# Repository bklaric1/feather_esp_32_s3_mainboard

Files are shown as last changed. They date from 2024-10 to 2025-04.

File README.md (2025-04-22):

# feather_esp_32_s3_mainboard

## PCBs for a project at Technical University of Applied Science Augsburg

### Explanation
This repo contains the KiCad 8 files for the main board and the daughter board of the project.  
Necessary files are located in the source folders with the corresponding names, whilst the 3D-models, symbols and footprints can be found in the models, symbols, and footprints folders.  
The rules files are located in the source folders, and correspond with the [2 Layer HD Design Rules](https://community.aisler.net/t/2-layer-hd-design-rules/3732) from Aisler DE.  
The BOM files are located in the source folders in the *bom* folder. They are created using [Interactive HTML Bom](https://github.com/openscopeproject/InteractiveHtmlBom) Plugin. To view the BOM file, clone the repo and open them locally.  
The idea of the design is to make a battery powered system with [Adafruit ESP32-S3 Feather](https://www.adafruit.com/product/5477) as the microcontroller to control the e-paper display. We used the [7.5 inch tri-color electronic paper display](https://www.good-display.com/product/394.html) with the partial refresh as our e-paper display, but any e-paper display from [Good Display](https://www.good-display.com) and from [Waveshare](https://www.waveshare.com) would work, as there is an integrated 3.3V to 5V Boost-Converter which can be turned on if needed (per switch).  
The system is made up from two main PCBs, one that houses the microcontroller and the other which serves as a front panel Board for the buttons.  
All the parts, except the microcontroller, are sponsored by Würth Elektronik. Many thanks to them, as without them sponsoring the parts, the production of the boards would be too expensive for a student project.  
The case for the display, PCBs, and the battery pack are all designed by us and 3D printed.  

### Mainboard
The main board houses the already mentioned Adafruit ESP32-S3 Feather microcontroller. We used the version with 4 MB Flash and 2 MB PSRAM, as we needed the RAM to store a part of firmware on it (static images). The pinout is the same as some other version, so the PCB Design can be used with them as well.  
As already mentioned, there is a 3.3V to 5V Boost-Converter implemented on the board. It is found in the configuration provided by the Würth Elektronik. To switch the output voltage on the display's voltage pin, one needs to only move the switch in another position, as labeled on the board.  
The pinout for the display connector corresponds to the two display manufactures I mentioned above, but check the pinouts before connecting.  
The connector for the board is the connector that links the two boards together.  
Implementation of the external reset button isn't fully finished, but rather left as two pins on the board. I wasn't sure if we'll need to move the reset button somewhere more accessible, so I left it like that. There is no need for another reset button on the board because the microcontroller already features a built-in reset button.  
I also brought the IIC pins out on the board, in case a sensor is need later. These pins are already used internally for the battery monitoring through the MAX17048 chip.  
The battery connection is found directly on the microcontroller module. It is the JST 2-PH plug.  
The microSD adapter is designed by the specification of the espressif themselves, according to their [README](https://github.com/espressif/esp-idf/blob/master/examples/storage/sd_card/sdmmc/README.md). I also fully modified the design to make it possible to switch from the 4-wire connection (SD mode) to the 1-wire connection (SPI), in case we need more GPIO pins for something else.

### Daugtherboard
The design of the daughter board is very simple. It only includes the four buttons with the debouncing design respectively. 
The connector links with the main board to make the system complete.
Board only has one mounting hole, because of the maximum length constrains. We designed the plugin spot for the board on one side, similar to the M.2 SSD mounting technology.

### Battery Pack
As we needed to build a battery powered system, we researched and put together a battery pack with 10 600 mAh and the nominal voltage of 3.7V (4.2V) fully charged.  
The battery pack consists of two 21700 Li-Ion batteries. We have chosen [these](https://www.akkuteile.de/lithium-ionen-akkus/21700/bak/bak-n21700cd-53e-mit-5300mah-10a-3-6v-3-7v-li-ionen-akku_100625_3323) because of the high capacity and small form factor.  
Though any combination of the batteries would work, we decided to maximize the space we have in the case and the budget of our project. That is why we selected these specific cells.  
We also included the already developed [BMS](https://www.akkuteile.de/1s-pcb-keeppower-xzd-1s5530-schutzelektronik-7a_200501_1407) (Battery Management System) PCB to protect the batteries of the deep discharge, overcharge and short circuit.

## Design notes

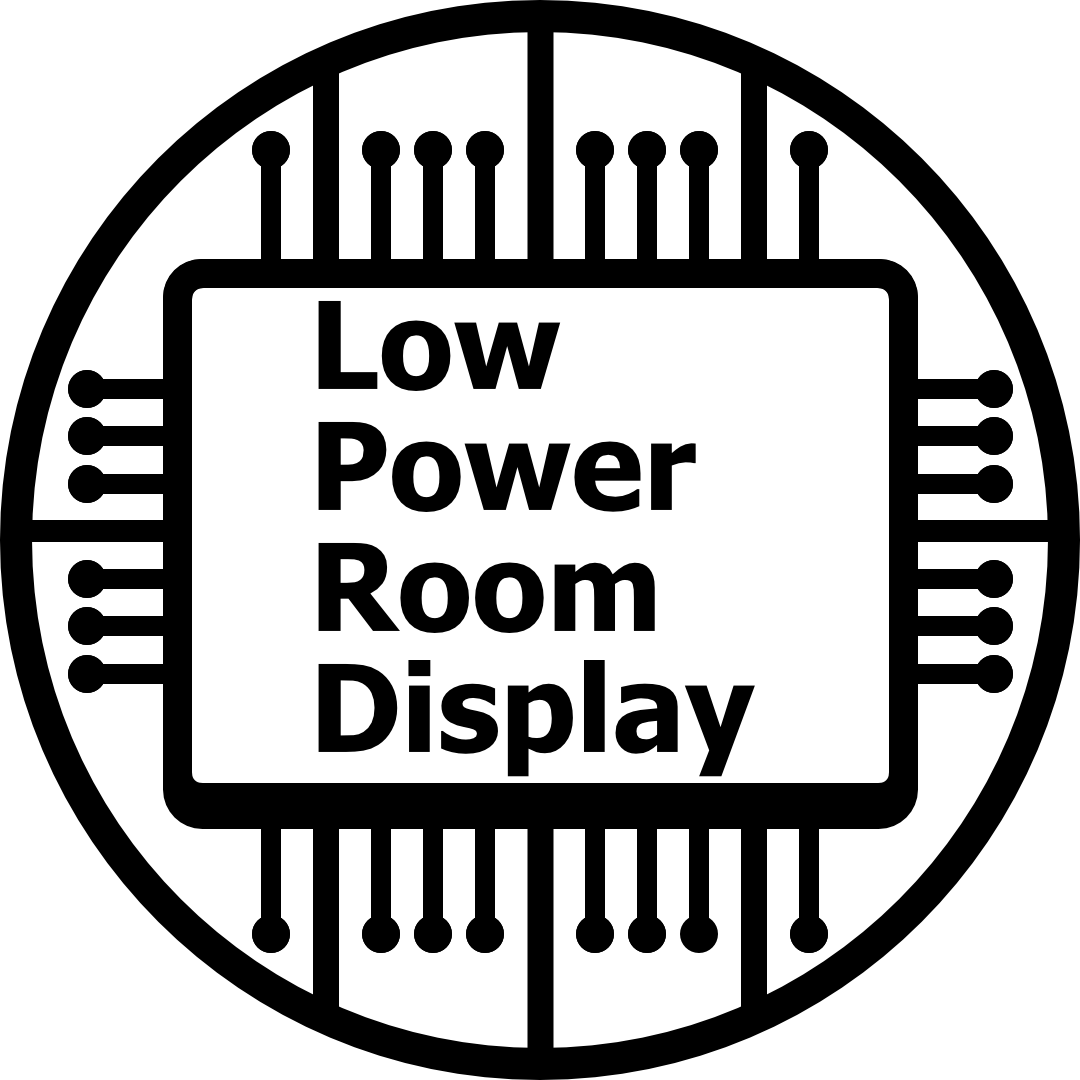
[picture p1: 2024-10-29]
models/Outline.png

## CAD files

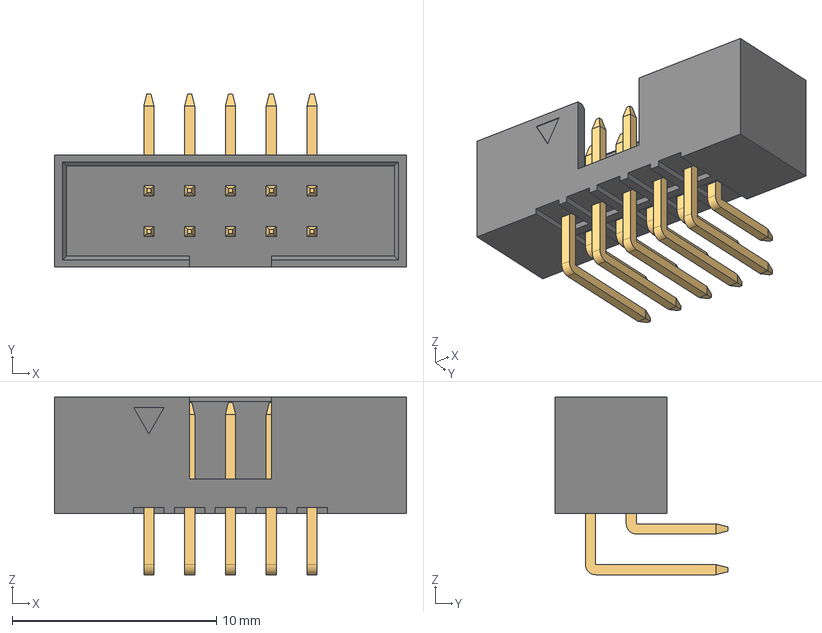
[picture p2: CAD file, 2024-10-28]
models/6250XX21721_62501021721.step
17.2 x 8.50 x 8.70 mm
6250xx21721_PIN x 5
6250xx21721_PIN_LONG x 5

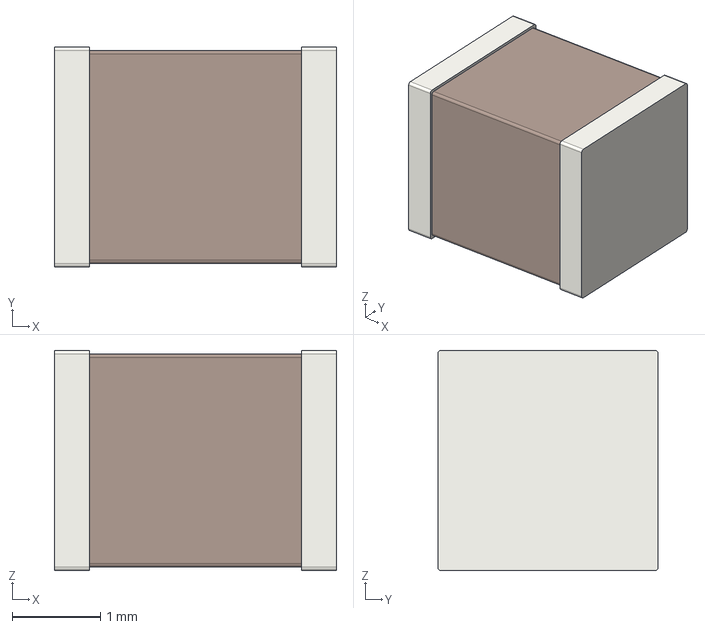
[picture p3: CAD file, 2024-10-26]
models/C_1210_3225Metric.step
3.20 x 2.50 x 2.50 mm

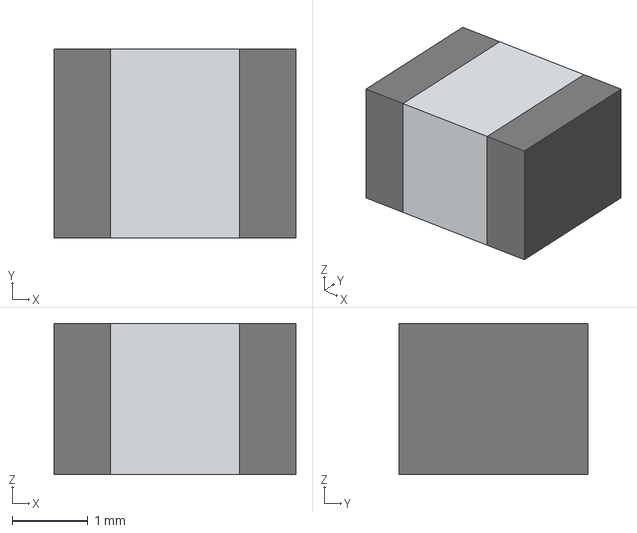
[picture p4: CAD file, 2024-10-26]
models/STP_885012x090xx (rev1).stp
3.20 x 2.50 x 2.00 mm
Body_3.2x2.5x2.0x0.75
Contact_2.5x2x0.75 x 2

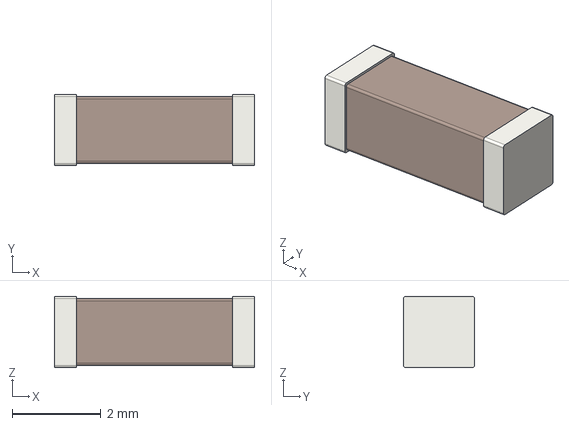
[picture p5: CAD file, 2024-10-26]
models/C_1806_4516Metric.step
4.50 x 1.60 x 1.60 mm

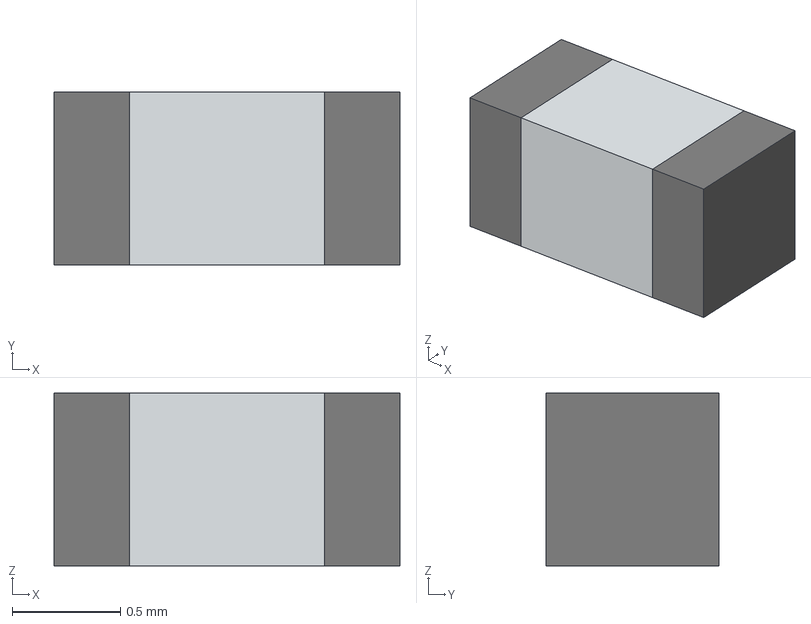
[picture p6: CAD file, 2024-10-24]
models/WCAP-CSGP_0603.step
1.60 x 0.8 x 0.8 mm
Body_1.6x0.8x0.8x0.35
Contact_0.8x0.8x0.35 x 2

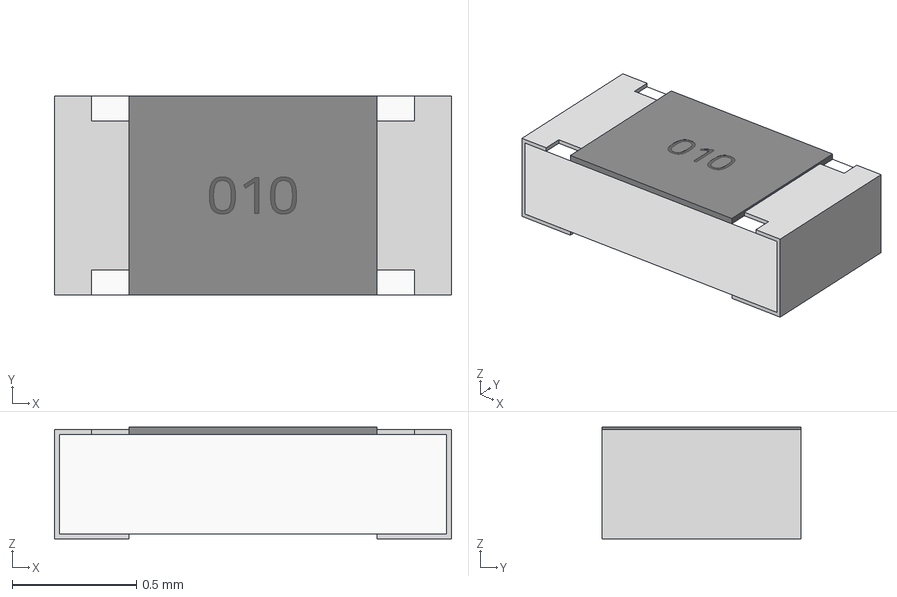
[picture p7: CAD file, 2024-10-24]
models/STP_WRIS-RSKS_0603_rev1.stp
1.60 x 0.8 x 0.45 mm
Pins
Cover

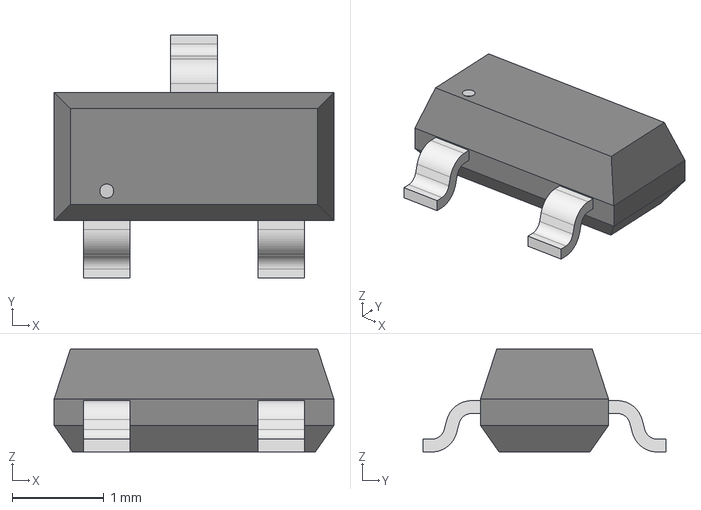
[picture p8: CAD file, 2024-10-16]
models/SOT_02K-T1-GE3_VIS.step
3.05 x 2.64 x 1.12 mm

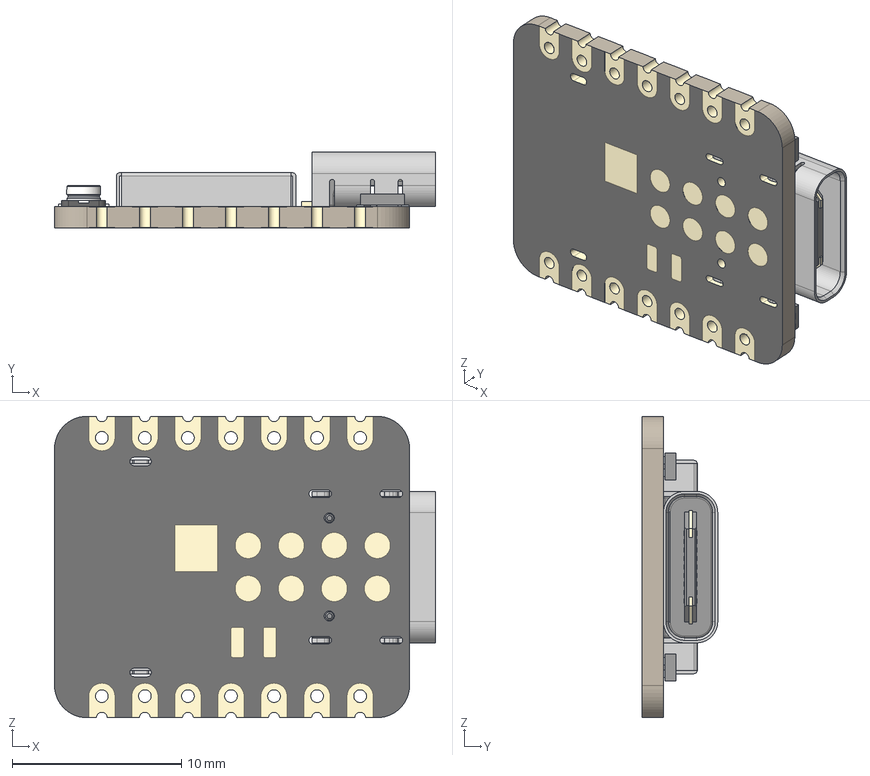
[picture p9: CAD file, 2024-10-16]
models/XIAO-ESP32S3 v2.step
22.5 x 4.46 x 17.8 mm
BOSS-EXTRUDE14_8_
BOSS-EXTRUDE7_4_
BOSS-EXTRUDE7_3_
BOSS-EXTRUDE14_4_
BOSS-EXTRUDE14_2_
BOSS-EXTRUDE14_11_
BOSS-EXTRUDE7_7_
BOSS-EXTRUDE14_9_
BOSS-EXTRUDE14_3_
BOSS-EXTRUDE14_7_
MIRROR2
BOSS-EXTRUDE14_5_
BOSS-EXTRUDE14_12_
BOSS-EXTRUDE7_8_
BOSS-EXTRUDE7_1_
BOSS-EXTRUDE14_10_
BOSS-EXTRUDE7_9_
BOSS-EXTRUDE14_6_
BOSS-EXTRUDE14_1_
BOSS-EXTRUDE7_6_
BOSS-EXTRUDE7_2_
CUT-EXTRUDE5
BOSS-EXTRUDE7_5_
Shield
Pins x 2
U.FL-R-SMT-1_10_ v1

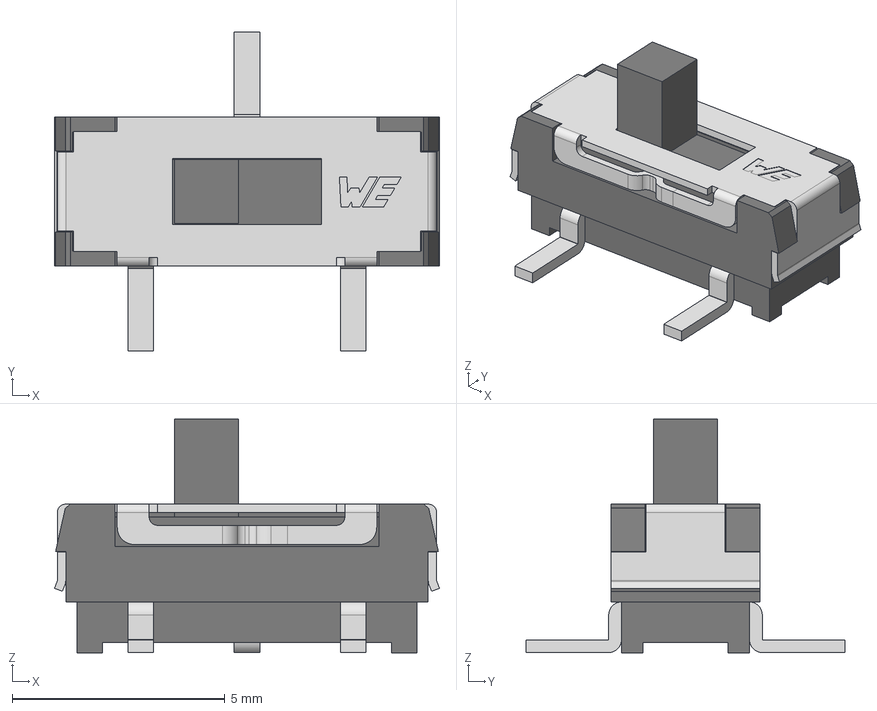
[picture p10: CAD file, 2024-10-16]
models/WS-SLSV_450406020024 (rev1).stp
9.05 x 7.50 x 5.50 mm
Base
Actuator
cover

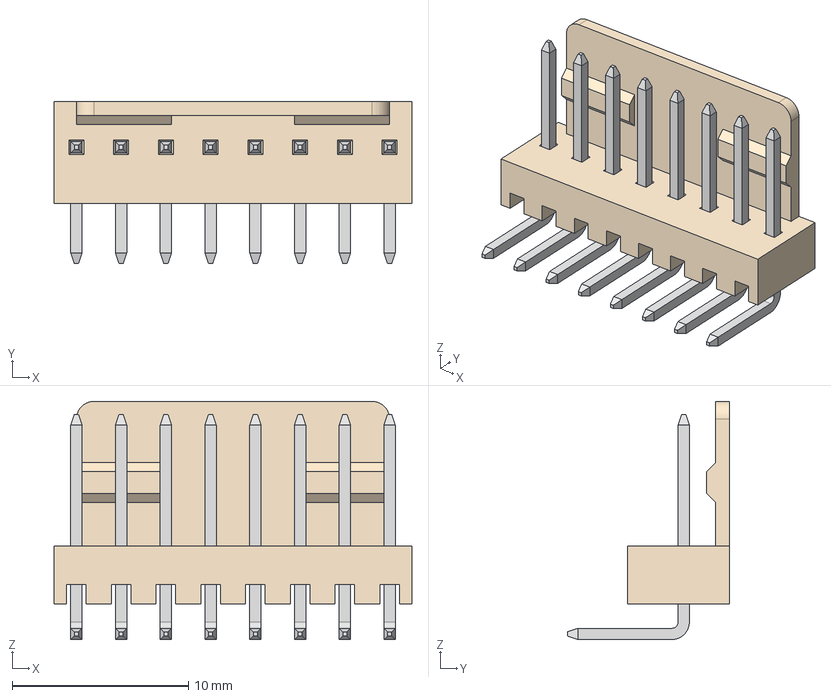
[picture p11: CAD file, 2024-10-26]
models/61900819521.step
20.3 x 9.20 x 13.5 mm
6190xx1xx21_PIN x 8

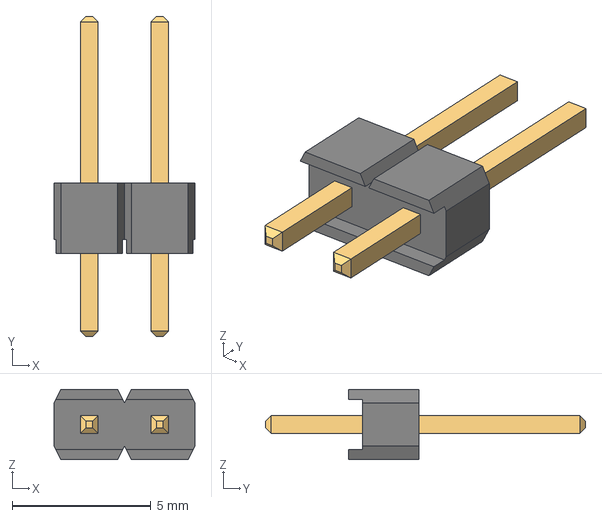
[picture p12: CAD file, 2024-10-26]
models/61300211121_rev1.stp
5.08 x 11.5 x 2.54 mm
6130xx11121_PIN x 2

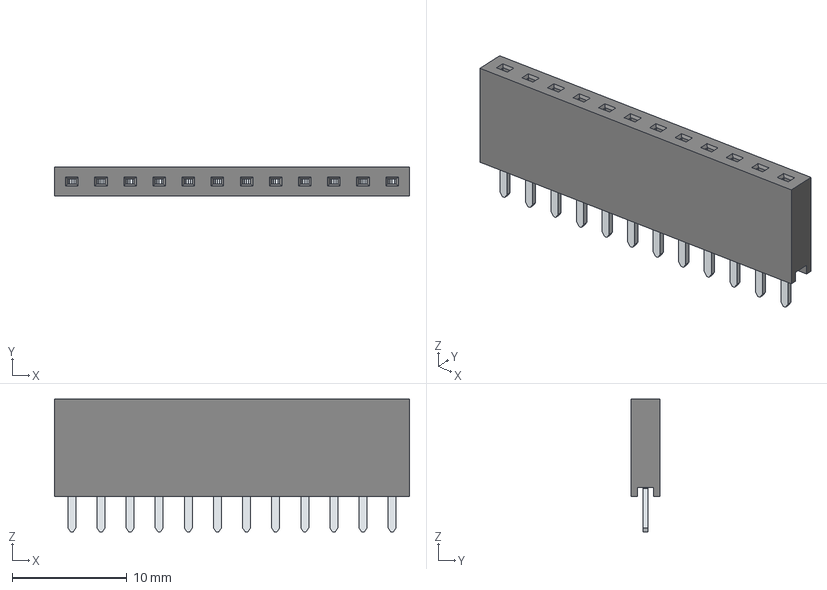
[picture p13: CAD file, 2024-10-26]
models/61301211821 (rev1).stp
31.0 x 2.50 x 11.6 mm

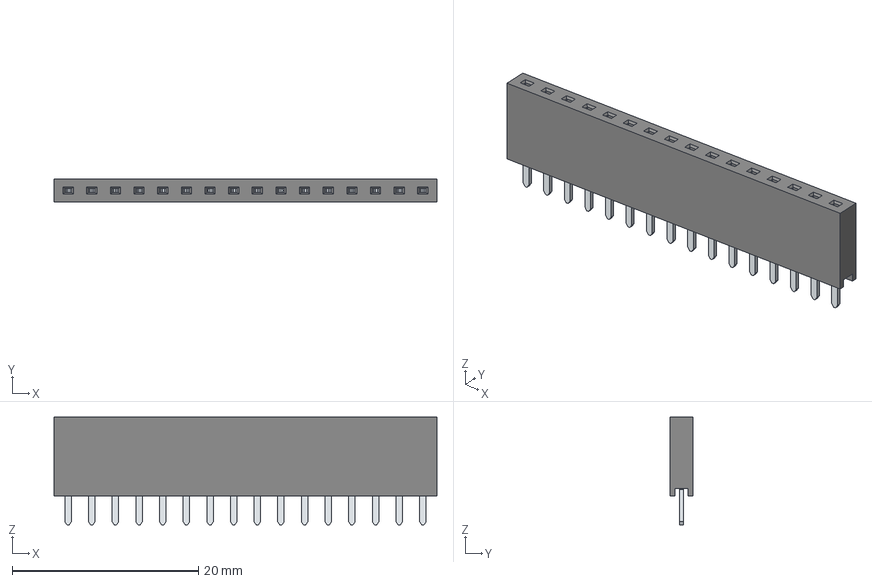
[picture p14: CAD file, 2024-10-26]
models/61301611821 (rev1).stp
41.1 x 2.50 x 11.6 mm

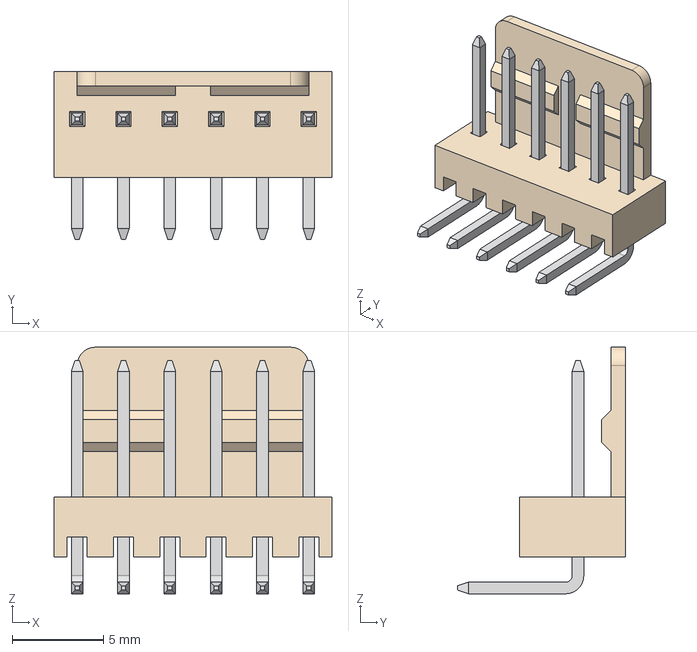
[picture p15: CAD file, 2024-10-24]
models/61900619521.step
15.2 x 9.20 x 13.5 mm
6190xx1xx21_PIN x 6

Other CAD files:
models/693071020811_rev1.stp
models/450405020524.step
models/744773033-56544.step
models/430182050816 (rev1).stp

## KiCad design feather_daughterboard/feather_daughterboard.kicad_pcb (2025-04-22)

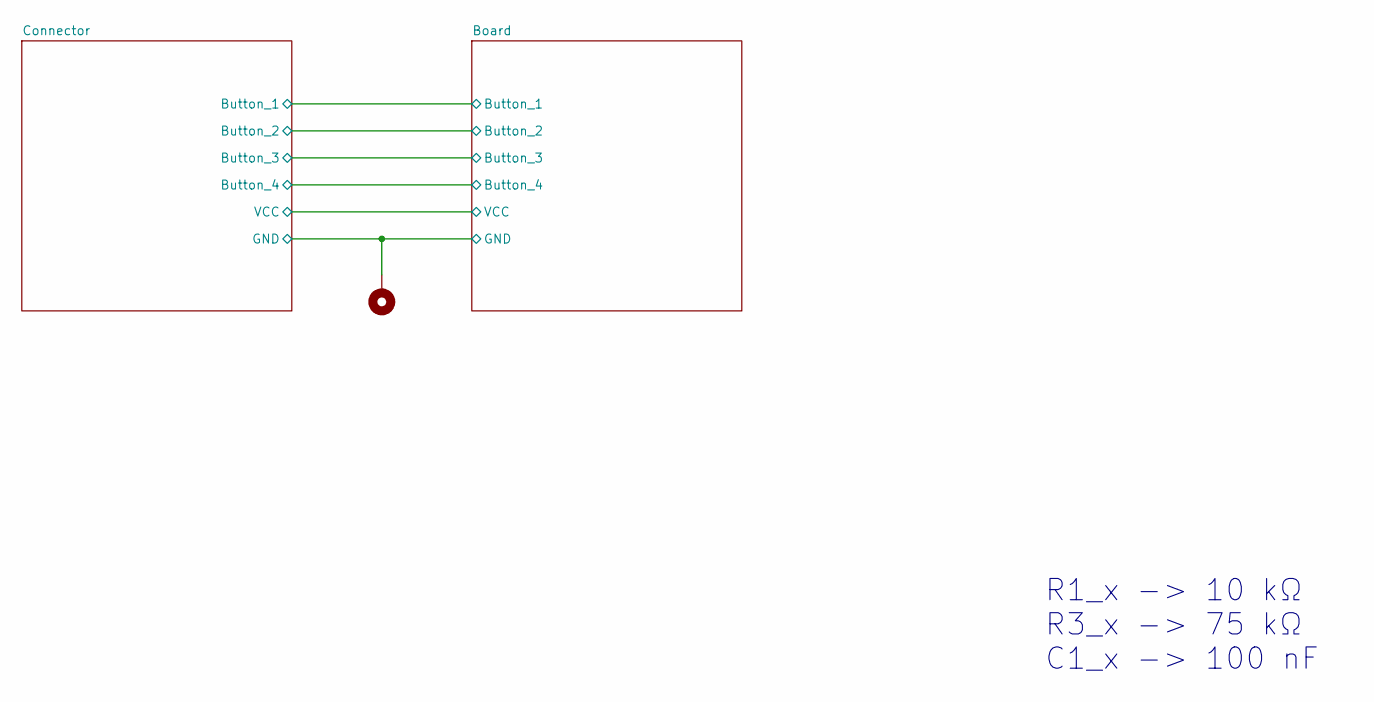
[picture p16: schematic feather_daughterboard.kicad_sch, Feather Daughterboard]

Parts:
H2: MountingHole_Pad; MountingHole_2.2mm_M2_DIN965_Pad

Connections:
/Board/GND: H2.1; also elsewhere on the board

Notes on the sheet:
R1_x -> 10 kΩ R3_x -> 75 kΩ C1_x -> 100 nF

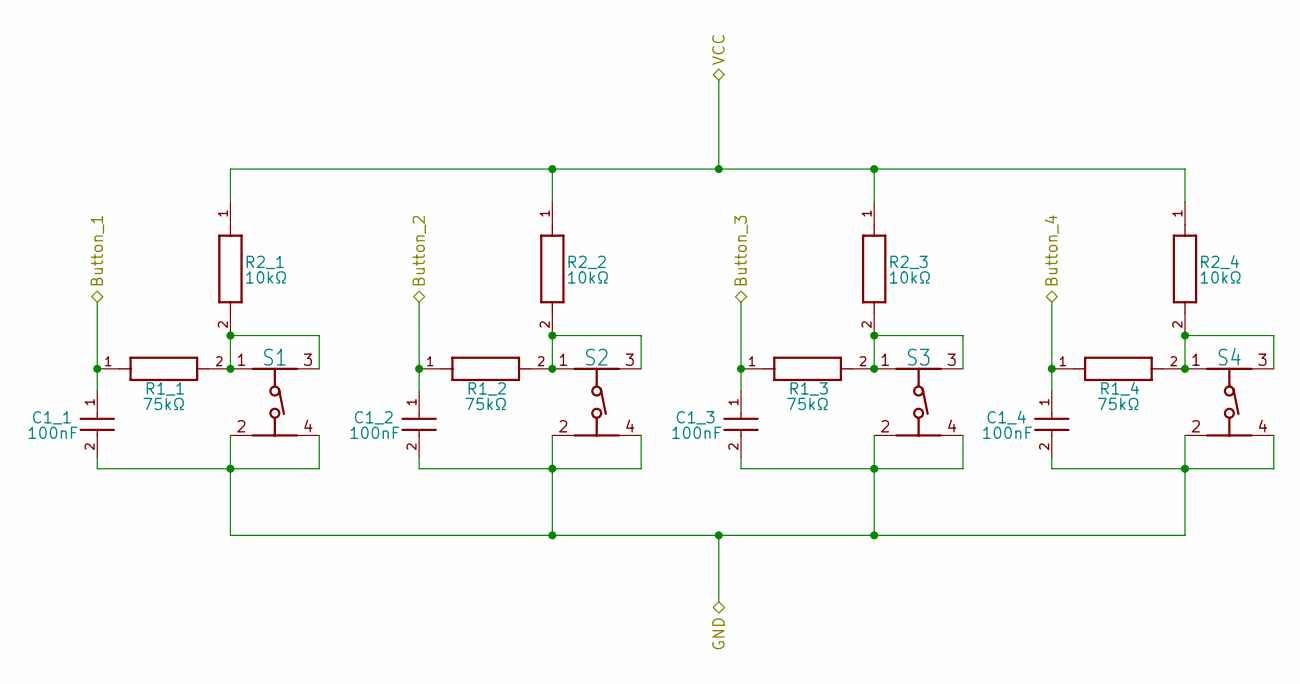
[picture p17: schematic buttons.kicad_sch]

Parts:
C1_1, C1_2, C1_3, C1_4: 100nF; WCAP-CSGP_0603_R
R1_1, R1_2, R1_3, R1_4: 75kΩ; WRIS-RSKS_0603_REFLOW
R2_1, R2_2, R2_3, R2_4: 10kΩ; WRIS-RSKS_0603_REFLOW
S1, S2, S3, S4: 430182050816

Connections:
/Board/Button_1: C1_1.1, R1_1.1; also elsewhere on the board
/Board/Button_2: C1_2.1, R1_2.1; also elsewhere on the board
/Board/Button_3: C1_3.1, R1_3.1; also elsewhere on the board
/Board/Button_4: C1_4.1, R1_4.1; also elsewhere on the board
/Board/GND: C1_1.2, C1_2.2, C1_3.2, C1_4.2, S1.2, S1.4, S2.2, S2.4, S3.2, S3.4, S4.2, S4.4; also elsewhere on the board
/Board/VCC: R2_1.1, R2_2.1, R2_3.1, R2_4.1; also elsewhere on the board
unnamed: R1_1.2, R2_1.2, S1.1, S1.3
unnamed: R1_2.2, R2_2.2, S2.1, S2.3
unnamed: R1_3.2, R2_3.2, S3.1, S3.3
unnamed: R1_4.2, R2_4.2, S4.1, S4.3

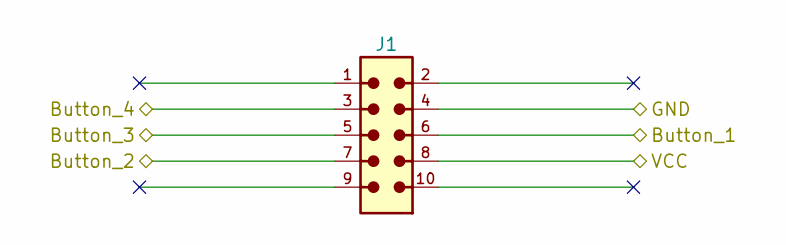
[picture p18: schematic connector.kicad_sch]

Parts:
J1: 6250XX21721_62501021721; 62501021721; PART-NUMBER 62501021721

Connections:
/Board/Button_1: J1.6; also elsewhere on the board
/Board/Button_2: J1.7; also elsewhere on the board
/Board/Button_3: J1.5; also elsewhere on the board
/Board/Button_4: J1.3; also elsewhere on the board
/Board/GND: J1.4; also elsewhere on the board
/Board/VCC: J1.8; also elsewhere on the board

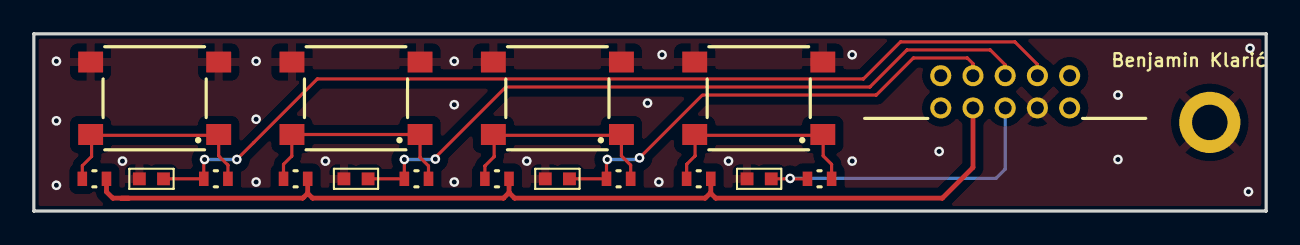
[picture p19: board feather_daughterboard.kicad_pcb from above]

Board: 2 copper layers, 76.5 x 11.0 mm, 18 parts (0 on the bottom side), 10 nets.

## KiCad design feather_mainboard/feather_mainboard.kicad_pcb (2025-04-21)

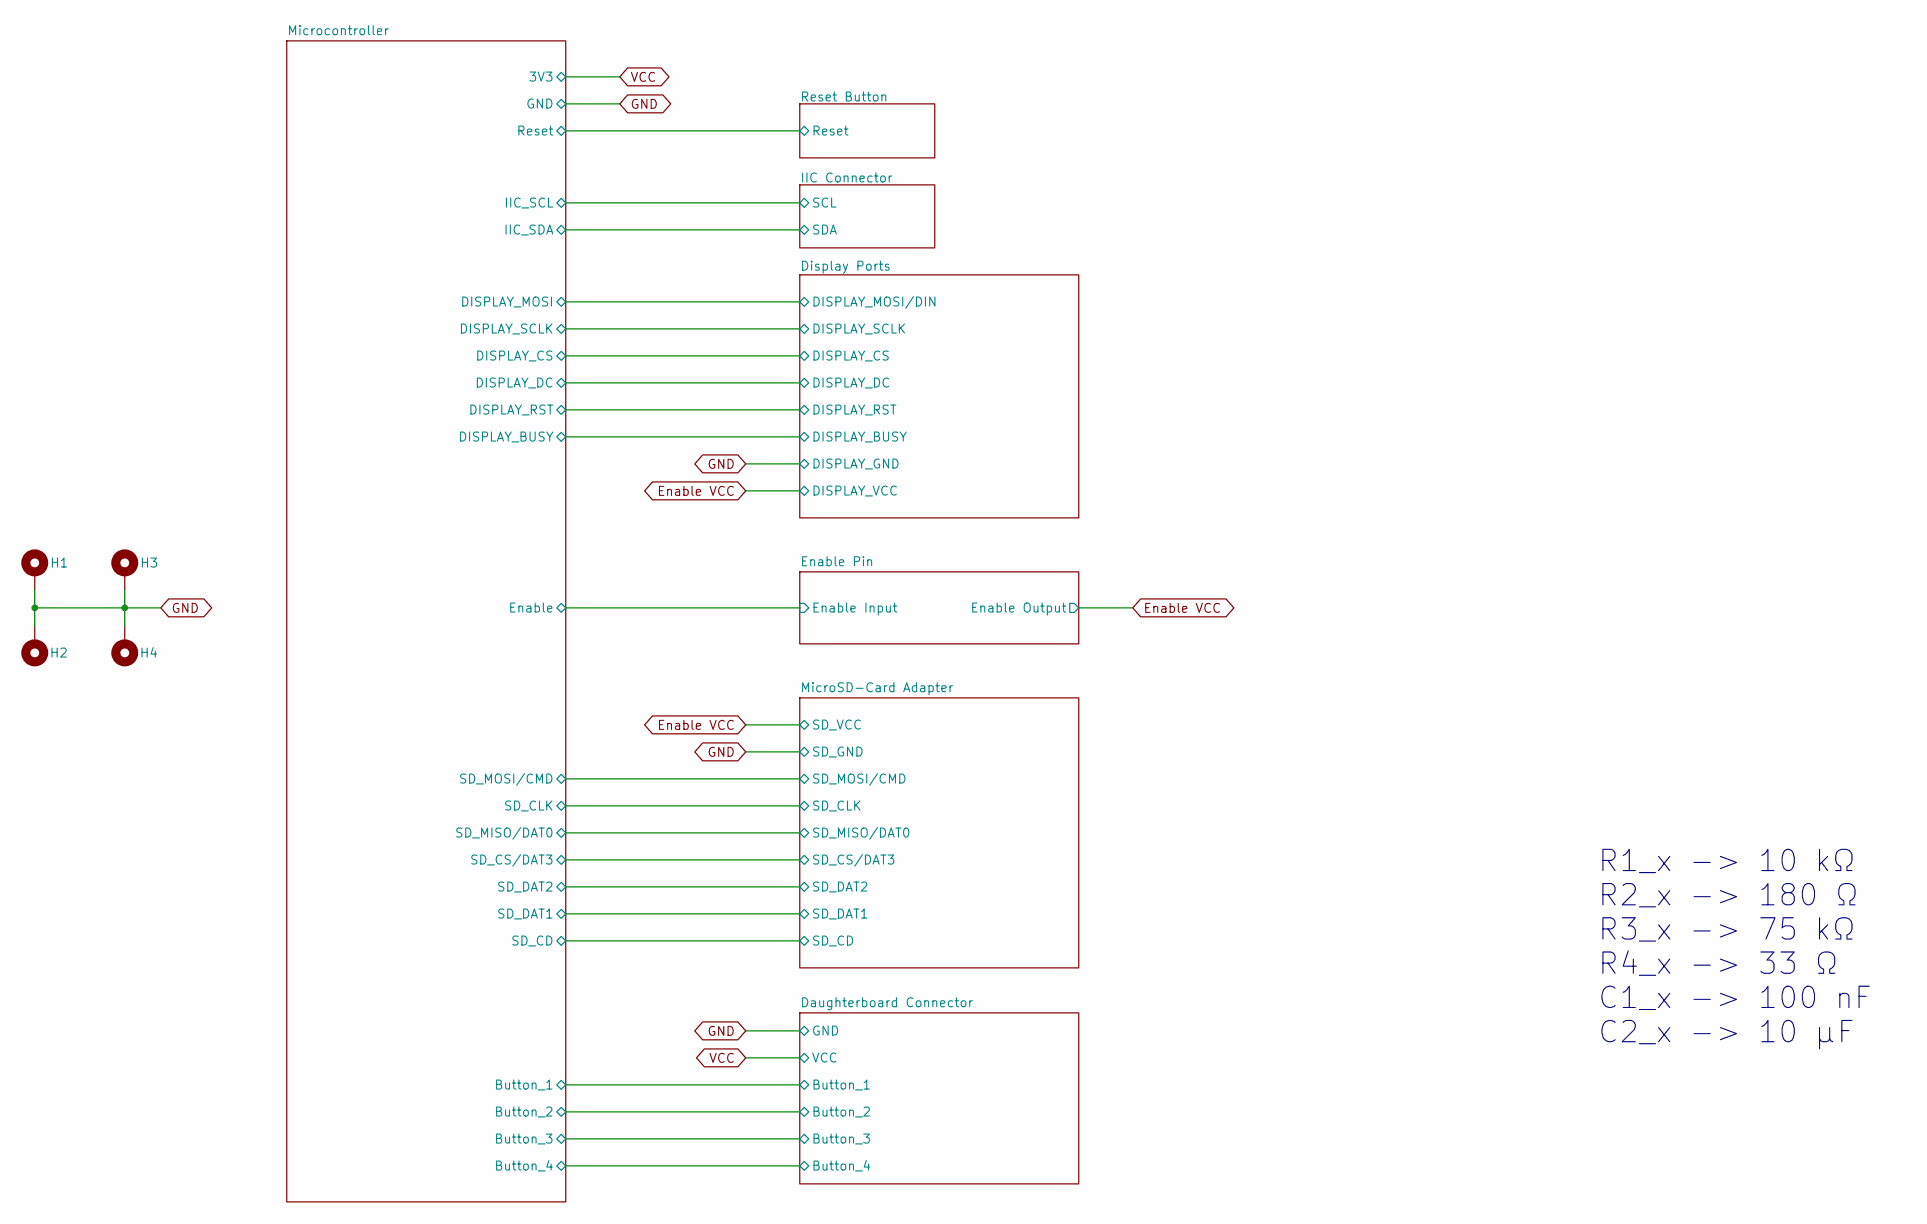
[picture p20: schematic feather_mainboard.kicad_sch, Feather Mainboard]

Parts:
H1, H2, H3, H4: MountingHole_Pad; MountingHole_2.2mm_M2_DIN965_Pad

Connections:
GND: H1.1, H2.1, H3.1, H4.1; also elsewhere on the board

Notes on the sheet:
R1_x -> 10 kΩ R2_x -> 180 Ω R3_x -> 75 kΩ R4_x -> 33 Ω C1_x -> 100 nF C2_x -> 10 µF

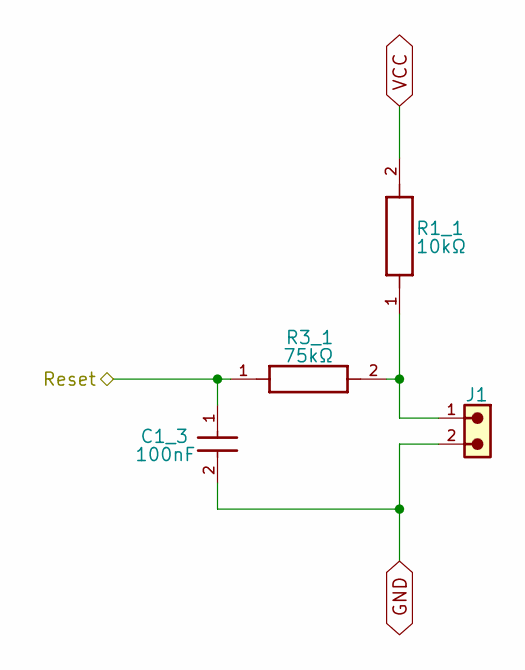
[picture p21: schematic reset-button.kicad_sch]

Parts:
C1_3: 100nF; WCAP-CSGP_0603_R
J1: 61300211121; PART-NUMBER 61300211121
R1_1: 10kΩ; WRIS-RSKS_0603_REFLOW
R3_1: 75kΩ; WRIS-RSKS_0603_REFLOW

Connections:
/Microcontroller/Reset: C1_3.1, R3_1.1; also elsewhere on the board
GND: C1_3.2, J1.2; also elsewhere on the board
unnamed: J1.1, R1_1.1, R3_1.2
VCC: R1_1.2; also elsewhere on the board

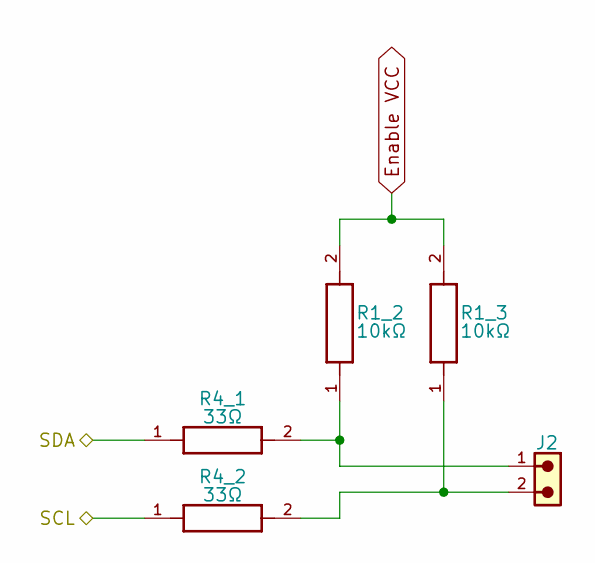
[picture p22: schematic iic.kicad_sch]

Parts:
J2: 61300211121; PART-NUMBER 61300211121
R1_2, R1_3: 10kΩ; WRIS-RSKS_0603_REFLOW
R4_1, R4_2: 33Ω; WRIS-RSKS_0603_REFLOW

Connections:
/IIC Connector/SCL: R4_2.1; also elsewhere on the board
/IIC Connector/SDA: R4_1.1; also elsewhere on the board
Enable VCC: R1_2.2, R1_3.2; also elsewhere on the board
unnamed: J2.1, R1_2.1, R4_1.2
unnamed: J2.2, R1_3.1, R4_2.2

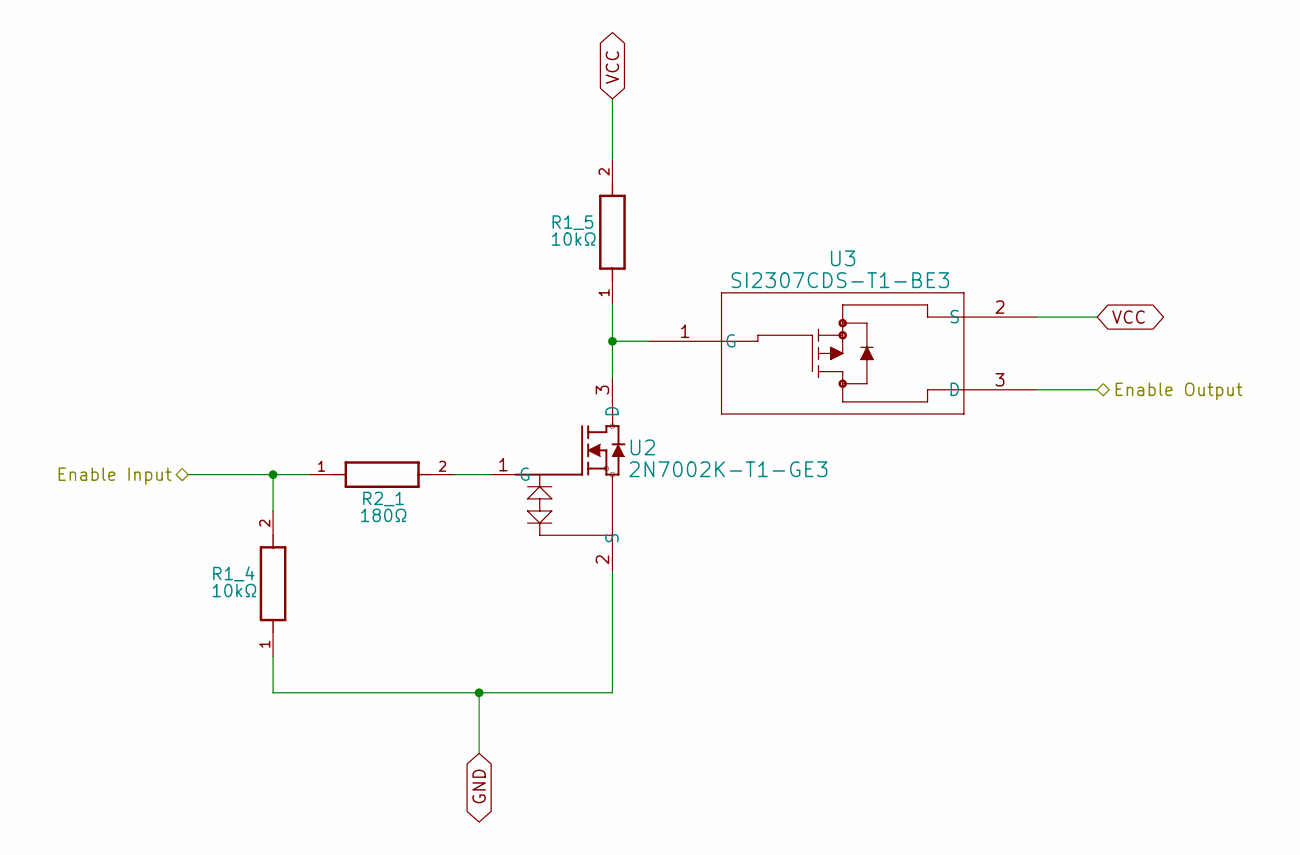
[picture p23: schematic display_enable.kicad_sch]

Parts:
R1_4, R1_5: 10kΩ; WRIS-RSKS_0603_REFLOW
R2_1: 180Ω; WRIS-RSKS_0603_REFLOW
U2: 2N7002K-T1-GE3; SOT_02K-T1-GE3_VIS
U3: SI2307CDS-T1-BE3; SOT-23_VIS

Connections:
/Enable Pin/Enable Input: R1_4.2, R2_1.1; also elsewhere on the board
Enable VCC: U3.3 (D); also elsewhere on the board
GND: R1_4.1, U2.2 (S); also elsewhere on the board
unnamed: R1_5.1, U2.3 (D), U3.1 (G)
unnamed: R2_1.2, U2.1 (G)
VCC: R1_5.2, U3.2 (S); also elsewhere on the board

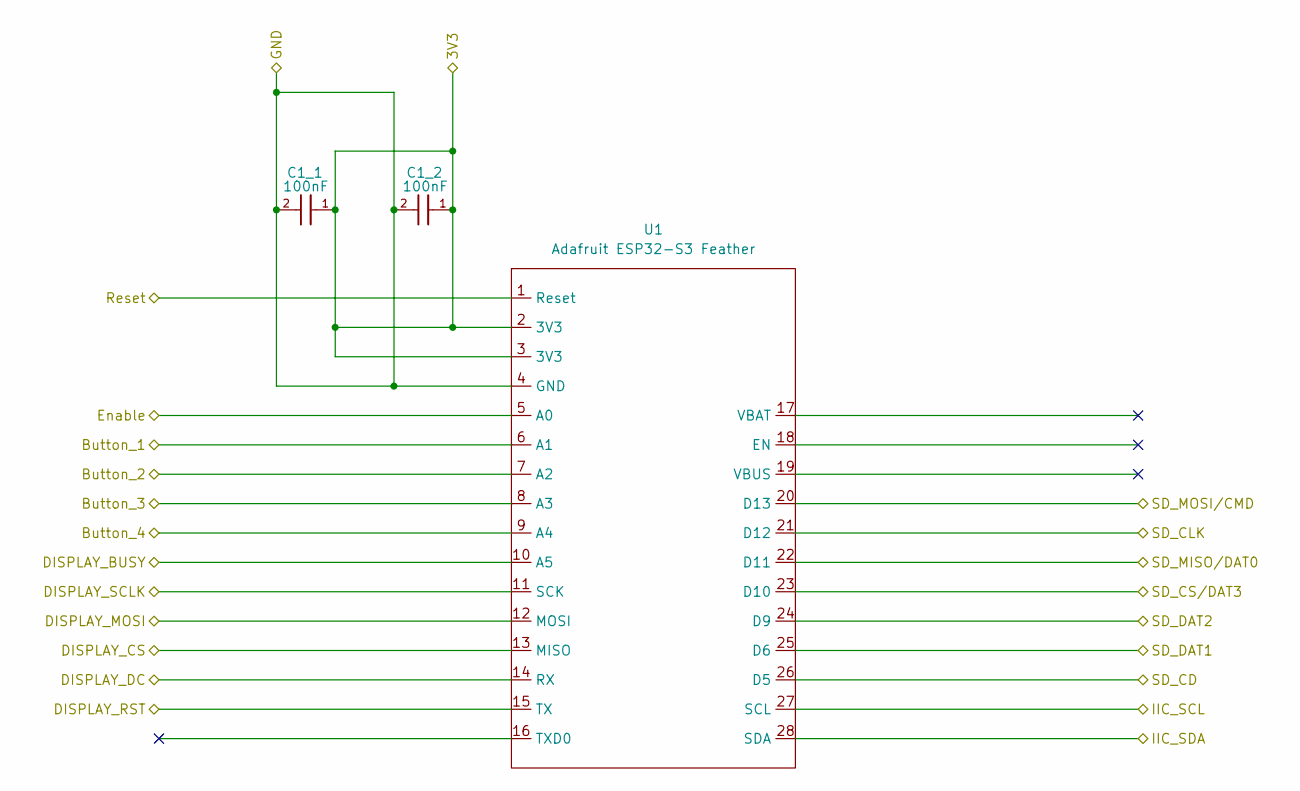
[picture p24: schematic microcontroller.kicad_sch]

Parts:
C1_1, C1_2: 100nF; WCAP-CSGP_0603_R
U1: Adafruit ESP32-S3 Feather; Adafruit ESP32-S3 Feather 4MB Flash 2MB PSRAM

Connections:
/Daughterboard Connector/Button_1: U1.6 (A1); also elsewhere on the board
/Daughterboard Connector/Button_2: U1.7 (A2); also elsewhere on the board
/Daughterboard Connector/Button_3: U1.8 (A3); also elsewhere on the board
/Daughterboard Connector/Button_4: U1.9 (A4); also elsewhere on the board
/Display Ports/DISPLAY_BUSY: U1.10 (A5); also elsewhere on the board
/Display Ports/DISPLAY_CS: U1.13 (MISO); also elsewhere on the board
/Display Ports/DISPLAY_DC: U1.14 (RX); also elsewhere on the board
/Display Ports/DISPLAY_MOSI/DIN: U1.12 (MOSI); also elsewhere on the board
/Display Ports/DISPLAY_RST: U1.15 (TX); also elsewhere on the board
/Display Ports/DISPLAY_SCLK: U1.11 (SCK); also elsewhere on the board
/Enable Pin/Enable Input: U1.5 (A0); also elsewhere on the board
/IIC Connector/SCL: U1.27 (SCL); also elsewhere on the board
/IIC Connector/SDA: U1.28 (SDA); also elsewhere on the board
/MicroSD-Card Adapter/SD_CD: U1.26 (D5); also elsewhere on the board
/MicroSD-Card Adapter/SD_CLK: U1.21 (D12); also elsewhere on the board
/MicroSD-Card Adapter/SD_CS/DAT3: U1.23 (D10); also elsewhere on the board
/MicroSD-Card Adapter/SD_DAT1: U1.25 (D6); also elsewhere on the board
/MicroSD-Card Adapter/SD_DAT2: U1.24 (D9); also elsewhere on the board
/MicroSD-Card Adapter/SD_MISO/DAT0: U1.22 (D11); also elsewhere on the board
/MicroSD-Card Adapter/SD_MOSI/CMD: U1.20 (D13); also elsewhere on the board
/Microcontroller/Reset: U1.1 (Reset); also elsewhere on the board
GND: C1_1.2, C1_2.2, U1.4 (GND); also elsewhere on the board
VCC: C1_1.1, C1_2.1, U1.2 (3V3), U1.3 (3V3); also elsewhere on the board

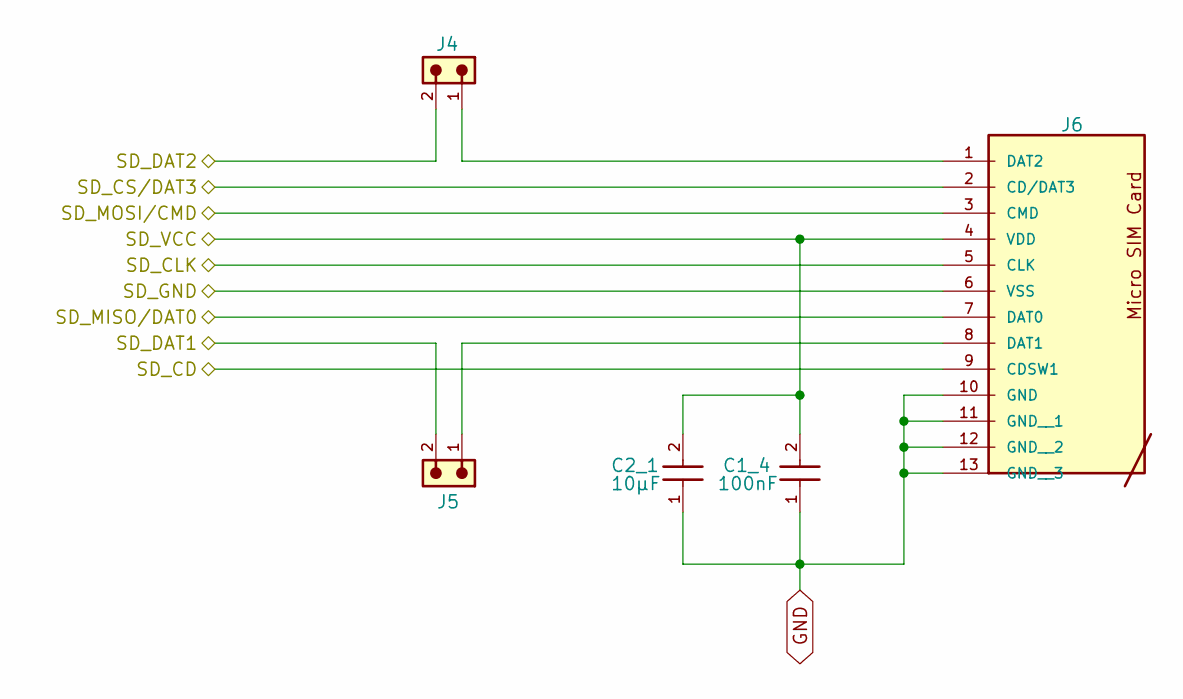
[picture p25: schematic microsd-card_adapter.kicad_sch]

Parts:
C1_4: 100nF; WCAP-CSGP_0603_R
C2_1: 10µF; WCAP-CSGP_0603_R
J4, J5: 61300211121; PART-NUMBER 61300211121
J6: 693071020811; PART-NUMBER 693071020811

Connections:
/MicroSD-Card Adapter/SD_CD: J6.9 (CDSW1); also elsewhere on the board
/MicroSD-Card Adapter/SD_CLK: J6.5 (CLK); also elsewhere on the board
/MicroSD-Card Adapter/SD_CS/DAT3: J6.2 (CD/DAT3); also elsewhere on the board
/MicroSD-Card Adapter/SD_DAT1: J5.2; also elsewhere on the board
/MicroSD-Card Adapter/SD_DAT2: J4.2; also elsewhere on the board
/MicroSD-Card Adapter/SD_MISO/DAT0: J6.7 (DAT0); also elsewhere on the board
/MicroSD-Card Adapter/SD_MOSI/CMD: J6.3 (CMD); also elsewhere on the board
Enable VCC: C1_4.2, C2_1.2, J6.4 (VDD); also elsewhere on the board
GND: C1_4.1, C2_1.1, J6.6 (VSS), J6.10 (GND), J6.11 (GND__1), J6.12 (GND__2), J6.13 (GND__3); also elsewhere on the board
unnamed: J5.1, J6.8 (DAT1)
unnamed: J4.1, J6.1 (DAT2)

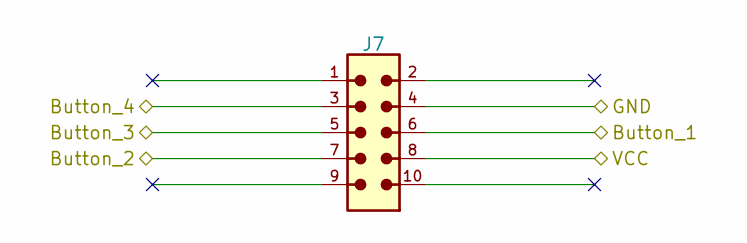
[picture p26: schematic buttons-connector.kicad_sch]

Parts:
J7: 62501021721; 62501021721_full; PART-NUMBER 62501021721

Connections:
/Daughterboard Connector/Button_1: J7.6; also elsewhere on the board
/Daughterboard Connector/Button_2: J7.7; also elsewhere on the board
/Daughterboard Connector/Button_3: J7.5; also elsewhere on the board
/Daughterboard Connector/Button_4: J7.3; also elsewhere on the board
GND: J7.4; also elsewhere on the board
VCC: J7.8; also elsewhere on the board

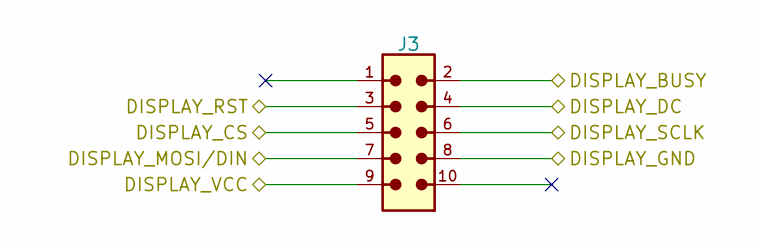
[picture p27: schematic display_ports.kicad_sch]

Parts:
J3: 62501021721; 62501021721_full; PART-NUMBER 62501021721

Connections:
/Display Ports/DISPLAY_BUSY: J3.2; also elsewhere on the board
/Display Ports/DISPLAY_CS: J3.5; also elsewhere on the board
/Display Ports/DISPLAY_DC: J3.4; also elsewhere on the board
/Display Ports/DISPLAY_MOSI/DIN: J3.7; also elsewhere on the board
/Display Ports/DISPLAY_RST: J3.3; also elsewhere on the board
/Display Ports/DISPLAY_SCLK: J3.6; also elsewhere on the board
Enable VCC: J3.9; also elsewhere on the board
GND: J3.8; also elsewhere on the board


Board: 2 copper layers, 60.0 x 60.0 mm, 28 parts (0 on the bottom side), 31 nets.

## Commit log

2024-10-16 added parts of the schematics that were already used by the xiao_mainboard, as we want to be as backwards compatible as possible
    [430182050816 (rev1).stp, 744773033--3DModel-STEP-56544.step, SOT_02K-T1-GE3_VIS.step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]
2024-10-19 finished microcontroller and microsd card subsheets. TODO: button subsheets and internal connections
    [450405020524.step, MEM2090-00-145-00-A.stp, buttons.kicad_sch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]
2024-10-20 schematic is almost done (check TODOs in schematic file)
    [693071020811.step, MEM2090-00-145-00-A.stp, boost_converter.kicad_sch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]
2024-10-20 changed footprints location to match the new folder. TODO: check if the path is working on another computer
    [693071020811.step, MEM2090-00-145-00-A.stp, boost_converter.kicad_sch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]
2024-10-24 added daughter board
    [61900619521.step, STP_WRIS-RSKS_0603_rev1.stp, WCAP-CSGP_0603.step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]
2024-10-25 finished daughter board
    [buttons-connector.kicad_sch, display_ports.kicad_sch, feather_daughterboard.kicad_pcb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]
2024-10-26 finished mainboard design, need to do the routing
    [61300211121_rev1.stp, 61301211821 (rev1).stp, 61301611821 (rev1).stp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]
2024-10-26 finished the mainboard, added bom files
    [feather_daughterboard.kicad_pcb, feather_mainboard.kicad_pcb]
2024-10-27 moved the logo and did some small changes
    [feather_mainboard.kicad_pcb]
2024-10-27 added pins for the sd connections
    [feather_mainboard.kicad_pcb, microsd-card_adapter.kicad_sch]
2024-10-28 changed the connector on the daughter board
    [6250XX21721_62501021721.step, MEM2090-00-145-00-A.stp, buttons.kicad_sch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]
2024-10-28 finished mainboard and daughterboard
    [buttons-connector.kicad_sch, connector.kicad_sch, display_ports.kicad_sch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]
2024-10-29 added bigger logo and labeled the pins on the connectors
    [feather_daughterboard.kicad_pcb, feather_daughterboard.kicad_sch, feather_mainboard.kicad_pcb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]
2024-12-12 Corrected/switched the names of MISO and MOSI pins
    [boost_converter.kicad_sch, buttons-connector.kicad_sch, display_enable.kicad_sch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]
2025-02-04 Added V1.1: added a Shottky diode to block the parasitic feedback into the system from the SD adapter; routed the SD adapter pull-ups to the SD Vcc and not the uC Vcc; updated silkscreen text; cleane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
    [SDO_SOD123F_NEX.step, boost_converter.kicad_sch, buttons-connector.kicad_sch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]
2025-02-05 Small changes to silkscreen text
    [feather_daughterboard.kicad_sch, feather_mainboard.kicad_pcb]
2025-02-05 Small changed to daughterboard silkscreen text
    [feather_daughterboard.kicad_pcb]
2025-02-05 Removed the diode, since it is not needed
    [boost_converter.kicad_sch, buttons-connector.kicad_sch, display_enable.kicad_sch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]
2025-02-05 Removed diode files, as they are no longer needed
    [SDO_SOD123F_NEX.step, feather_mainboard.kicad_pcb]
2025-02-05 Updated silkscreen text
    [feather_mainboard.kicad_pcb]
2025-04-21 Updated the mainboard: removed unnecessary pull-ups on SD card lines; connected IIC pull-ups to enable circuit; cleaned up schematic
    [buttons-connector.kicad_sch, display_enable.kicad_sch, display_ports.kicad_sch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]
2025-04-21 Updated BOM and README
    [feather_mainboard.kicad_pcb]
2025-04-21 Updated Daughterboard and added Gerber files
    [feather_daughterboard-CuBottom.gbr, feather_daughterboard-CuTop.gbr, feather_daughterboard-EdgeCuts.gbr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]
2025-04-22 Small chanegs to Daughterboard; updated jlc export
    [connector.kicad_sch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]
2025-04-23 Updated jlc export of the mainboard
    [feather_mainboard-CuBottom.gbr, feather_mainboard-CuTop.gbr, feather_mainboard-EdgeCuts.gbr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]

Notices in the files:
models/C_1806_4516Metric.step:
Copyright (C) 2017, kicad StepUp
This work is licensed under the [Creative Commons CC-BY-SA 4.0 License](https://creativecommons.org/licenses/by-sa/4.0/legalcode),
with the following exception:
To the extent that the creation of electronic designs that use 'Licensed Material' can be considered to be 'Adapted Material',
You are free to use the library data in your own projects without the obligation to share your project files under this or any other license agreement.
